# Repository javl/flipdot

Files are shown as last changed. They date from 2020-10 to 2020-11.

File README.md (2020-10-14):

### Work in progress! This project is not completed yet!

# Flipdot
A controller for flipdot displays using the FP2800A BROSE chip. The schematic is heavily based on / pretty much a clone of [flippie](https://github.com/545ch4/flippie). See the flippie repo for a great explaination of how the BROSE displays are controlled.

Changes I have made / are planning on making are:

  * [X] Made in the open source Kicad instead of Eagle
  * [X] Replaced the TBD62783A which a A2982 as it seams easier to find
  * [ ] On-board power conversion instead of needing separate inputs for 3.3V, 5V and 24V

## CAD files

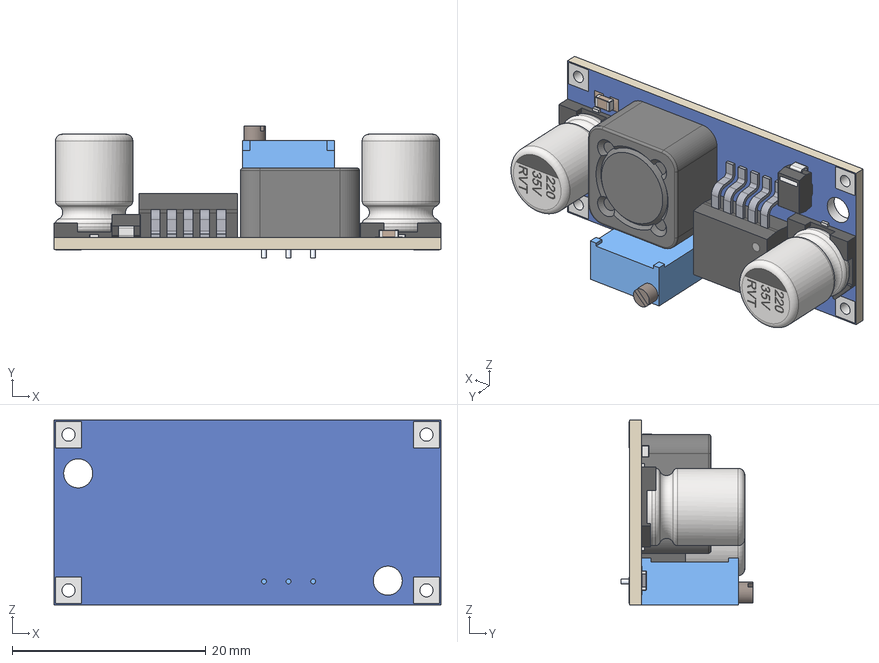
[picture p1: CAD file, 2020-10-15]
3dshapes/LM2596 DC-DC Buck Converter Module.stp
40.0 x 13.7 x 19.1 mm
CAPSMD220-35 x 2
Diode SMA
solder_hole x 4

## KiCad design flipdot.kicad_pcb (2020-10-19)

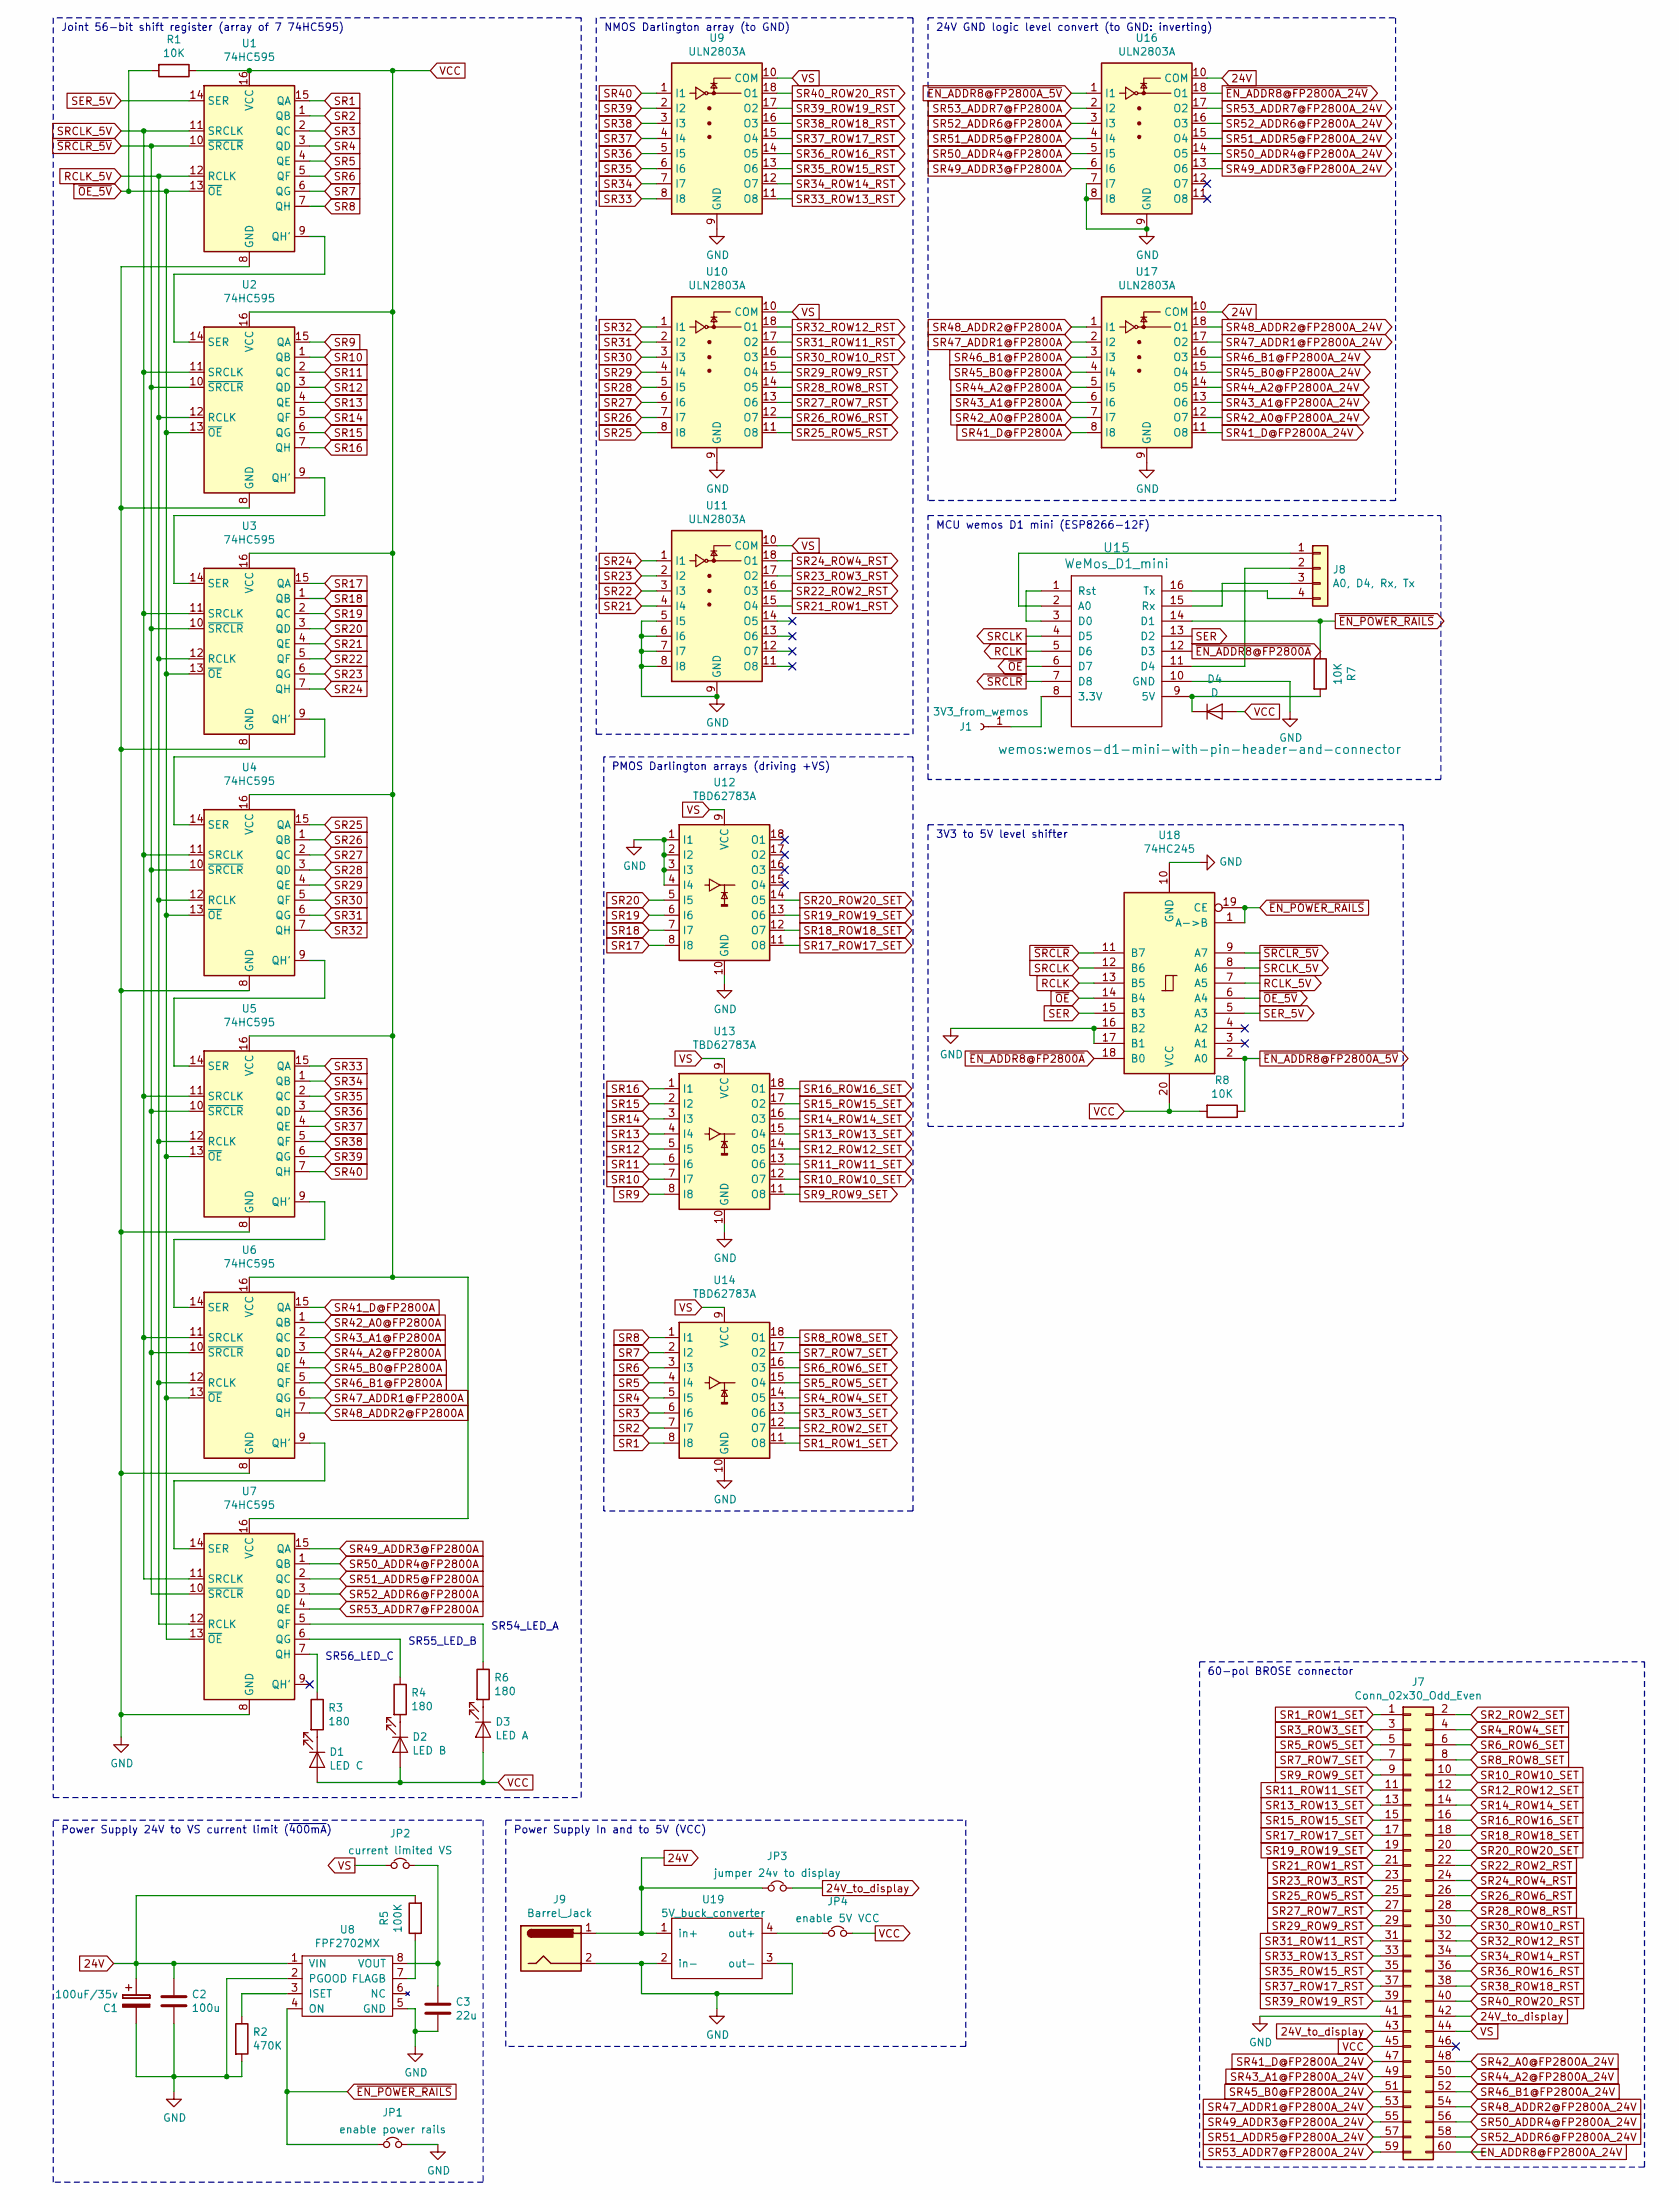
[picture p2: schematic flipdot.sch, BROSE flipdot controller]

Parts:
C1: 100uF/35v; CP_Elec_6.3x7.7
C2: 100u; CP_Radial_D6.3mm_P2.50mm
C3: 22u; CP_Radial_D5.0mm_P2.00mm
D1: LED C; LED_0805_2012Metric
D2: LED B; LED_0805_2012Metric
D3: LED A; LED_0805_2012Metric
D4: D; D_A-405_P7.62mm_Horizontal
J1: 3V3_from_wemos; PinHeader_1x01_P2.54mm_Vertical
J7: Conn_02x30_Odd_Even; PinHeader_2x30_P2.54mm_Vertical
J8: A0, D4, Rx, Tx; PinHeader_1x04_P2.54mm_Vertical
J9: Barrel_Jack; BarrelJack_Wuerth_6941xx301002
JP1: enable power rails; PinHeader_1x02_P2.54mm_Vertical
JP2: current limited VS; PinHeader_1x02_P2.54mm_Vertical
JP3: jumper 24v to display; PinHeader_1x02_P2.54mm_Vertical
JP4: enable 5V VCC; PinHeader_1x02_P2.54mm_Vertical
R1, R7, R8: 10K; R_0805_2012Metric
R2: 470K; R_0603_1608Metric
R3, R4, R6: 180; R_0603_1608Metric
R5: 100K; R_0603_1608Metric
U1, U2, U3, U4, U5, U6, U7: 74HC595; SOIC-16_3.9x9.9mm_P1.27mm
U8: FPF2702MX; SOIC-8_3.9x4.9mm_P1.27mm
U9, U10, U11, U16, U17: ULN2803A; SOIC-18W_7.5x11.6mm_P1.27mm
U12, U13, U14: TBD62783A; SOIC-20W_7.5x12.8mm_P1.27mm
U15: WeMos_D1_mini; wemos-d1-mini-with-pin-header-and-connector
U18: 74HC245; SO-20_12.8x7.5mm_P1.27mm
U19: 5V_buck_converter; 5v_buck_converter

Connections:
24V: C1.1, C2.1, J9.1, JP3.1, R5.2, U8.1 (VIN), U16.10 (COM), U17.10 (COM), U19.1 (in+)
24V_to_display: J7.42, J7.43, JP3.2
unnamed: C3.1, JP2.2, U8.8 (VOUT)
unnamed: D1.1 (K), R3.2
unnamed: D2.1 (K), R4.2
unnamed: D3.1 (K), R6.2
unnamed: D4.1 (K), R7.2, U15.9 (5V)
unnamed: J1.1, U15.8 (3.3V)
unnamed: J8.1, U15.2 (A0)
unnamed: J8.2, U15.11 (D4)
unnamed: J8.3, U15.15 (Rx)
unnamed: J8.4, U15.16 (Tx)
unnamed: JP4.1, U19.4 (out+)
unnamed: R2.1, U8.3 (ISET)
unnamed: R3.1, U7.7 (QH)
unnamed: R4.1, U7.6 (QG)
unnamed: R5.1, U8.7 (FLAGB)
unnamed: R6.1, U7.5 (QF)
unnamed: U1.9 (QH'), U2.14 (SER)
unnamed: U2.9 (QH'), U3.14 (SER)
unnamed: U3.9 (QH'), U4.14 (SER)
unnamed: U4.9 (QH'), U5.14 (SER)
unnamed: U5.9 (QH'), U6.14 (SER)
unnamed: U6.9 (QH'), U7.14 (SER)
unnamed: U15.1 (Rst), U15.3 (D0)
RCLK: U15.5 (D6), U18.13 (B5)
RCLK_5V: U1.12 (RCLK), U2.12 (RCLK), U3.12 (RCLK), U4.12 (RCLK), U5.12 (RCLK), U6.12 (RCLK), U7.12 (RCLK), U18.7 (A5)
SER: U15.13 (D2), U18.15 (B3)
SER_5V: U1.14 (SER), U18.5 (A3)
SR1: U1.15 (QA), U14.8 (I8)
SR1_ROW1_SET: J7.1, U14.11 (O8)
SR2: U1.1 (QB), U14.7 (I7)
SR2_ROW2_SET: J7.2, U14.12 (O7)
SR3: U1.2 (QC), U14.6 (I6)
SR3_ROW3_SET: J7.3, U14.13 (O6)
SR4: U1.3 (QD), U14.5 (I5)
SR4_ROW4_SET: J7.4, U14.14 (O5)
SR5: U1.4 (QE), U14.4 (I4)
SR5_ROW5_SET: J7.5, U14.15 (O4)
SR6: U1.5 (QF), U14.3 (I3)
SR6_ROW6_SET: J7.6, U14.16 (O3)
SR7: U1.6 (QG), U14.2 (I2)
SR7_ROW7_SET: J7.7, U14.17 (O2)
SR8: U1.7 (QH), U14.1 (I1)
SR8_ROW8_SET: J7.8, U14.18 (O1)
SR9: U2.15 (QA), U13.8 (I8)
SR9_ROW9_SET: J7.9, U13.11 (O8)
SR10: U2.1 (QB), U13.7 (I7)
SR10_ROW10_SET: J7.10, U13.12 (O7)
SR11: U2.2 (QC), U13.6 (I6)
SR11_ROW11_SET: J7.11, U13.13 (O6)
SR12: U2.3 (QD), U13.5 (I5)
SR12_ROW12_SET: J7.12, U13.14 (O5)
SR13: U2.4 (QE), U13.4 (I4)
SR13_ROW13_SET: J7.13, U13.15 (O4)
SR14: U2.5 (QF), U13.3 (I3)
SR14_ROW14_SET: J7.14, U13.16 (O3)
SR15: U2.6 (QG), U13.2 (I2)
SR15_ROW15_SET: J7.15, U13.17 (O2)
SR16: U2.7 (QH), U13.1 (I1)
SR16_ROW16_SET: J7.16, U13.18 (O1)
SR17: U3.15 (QA), U12.8 (I8)
SR17_ROW17_SET: J7.17, U12.11 (O8)
SR18: U3.1 (QB), U12.7 (I7)
SR18_ROW18_SET: J7.18, U12.12 (O7)
SR19: U3.2 (QC), U12.6 (I6)
SR19_ROW19_SET: J7.19, U12.13 (O6)
SR20: U3.3 (QD), U12.5 (I5)
SR20_ROW20_SET: J7.20, U12.14 (O5)
SR21: U3.4 (QE), U11.4 (I4)
SR21_ROW1_RST: J7.21, U11.15 (O4)
SR22: U3.5 (QF), U11.3 (I3)
SR22_ROW2_RST: J7.22, U11.16 (O3)
SR23: U3.6 (QG), U11.2 (I2)
SR23_ROW3_RST: J7.23, U11.17 (O2)
SR24: U3.7 (QH), U11.1 (I1)
SR24_ROW4_RST: J7.24, U11.18 (O1)
SR25: U4.15 (QA), U10.8 (I8)
SR25_ROW5_RST: J7.25, U10.11 (O8)
SR26: U4.1 (QB), U10.7 (I7)
SR26_ROW6_RST: J7.26, U10.12 (O7)
SR27: U4.2 (QC), U10.6 (I6)
SR27_ROW7_RST: J7.27, U10.13 (O6)
SR28: U4.3 (QD), U10.5 (I5)
SR28_ROW8_RST: J7.28, U10.14 (O5)
SR29: U4.4 (QE), U10.4 (I4)
SR29_ROW9_RST: J7.29, U10.15 (O4)
SR30: U4.5 (QF), U10.3 (I3)
SR30_ROW10_RST: J7.30, U10.16 (O3)
SR31: U4.6 (QG), U10.2 (I2)
SR31_ROW11_RST: J7.31, U10.17 (O2)
SR32: U4.7 (QH), U10.1 (I1)
SR32_ROW12_RST: J7.32, U10.18 (O1)
SR33: U5.15 (QA), U9.8 (I8)
SR33_ROW13_RST: J7.33, U9.11 (O8)
SR34: U5.1 (QB), U9.7 (I7)
SR34_ROW14_RST: J7.34, U9.12 (O7)
SR35: U5.2 (QC), U9.6 (I6)
SR35_ROW15_RST: J7.35, U9.13 (O6)
SR36: U5.3 (QD), U9.5 (I5)
SR36_ROW16_RST: J7.36, U9.14 (O5)
SR37: U5.4 (QE), U9.4 (I4)
SR37_ROW17_RST: J7.37, U9.15 (O4)
SR38: U5.5 (QF), U9.3 (I3)
SR38_ROW18_RST: J7.38, U9.16 (O3)
SR39: U5.6 (QG), U9.2 (I2)
SR39_ROW19_RST: J7.39, U9.17 (O2)
SR40: U5.7 (QH), U9.1 (I1)
SR40_ROW20_RST: J7.40, U9.18 (O1)
SR41_D@FP2800A: U6.15 (QA), U17.8 (I8)
SR41_D@FP2800A_24V: J7.47, U17.11 (O8)
SR42_A0@FP2800A: U6.1 (QB), U17.7 (I7)
SR42_A0@FP2800A_24V: J7.48, U17.12 (O7)
SR43_A1@FP2800A: U6.2 (QC), U17.6 (I6)
SR43_A1@FP2800A_24V: J7.49, U17.13 (O6)
SR44_A2@FP2800A: U6.3 (QD), U17.5 (I5)
SR44_A2@FP2800A_24V: J7.50, U17.14 (O5)
SR45_B0@FP2800A: U6.4 (QE), U17.4 (I4)
SR45_B0@FP2800A_24V: J7.51, U17.15 (O4)
SR46_B1@FP2800A: U6.5 (QF), U17.3 (I3)
SR46_B1@FP2800A_24V: J7.52, U17.16 (O3)
SR47_ADDR1@FP2800A: U6.6 (QG), U17.2 (I2)
SR47_ADDR1@FP2800A_24V: J7.53, U17.17 (O2)
SR48_ADDR2@FP2800A: U6.7 (QH), U17.1 (I1)
SR48_ADDR2@FP2800A_24V: J7.54, U17.18 (O1)
SR49_ADDR3@FP2800A: U7.15 (QA), U16.6 (I6)
SR49_ADDR3@FP2800A_24V: J7.55, U16.13 (O6)
SR50_ADDR4@FP2800A: U7.1 (QB), U16.5 (I5)
SR50_ADDR4@FP2800A_24V: J7.56, U16.14 (O5)
SR51_ADDR5@FP2800A: U7.2 (QC), U16.4 (I4)
SR51_ADDR5@FP2800A_24V: J7.57, U16.15 (O4)
SR52_ADDR6@FP2800A: U7.3 (QD), U16.3 (I3)
SR52_ADDR6@FP2800A_24V: J7.58, U16.16 (O3)
SR53_ADDR7@FP2800A: U7.4 (QE), U16.2 (I2)
SR53_ADDR7@FP2800A_24V: J7.59, U16.17 (O2)
SRCLK: U15.4 (D5), U18.12 (B6)
SRCLK_5V: U1.11 (SRCLK), U2.11 (SRCLK), U3.11 (SRCLK), U4.11 (SRCLK), U5.11 (SRCLK), U6.11 (SRCLK), U7.11 (SRCLK), U18.8 (A6)
VCC: D1.2 (A), D2.2 (A), D3.2 (A), D4.2 (A), J7.45, JP4.2, R1.1, R8.2, U1.16 (VCC), U2.16 (VCC), U3.16 (VCC), U4.16 (VCC), U5.16 (VCC), U6.16 (VCC), U7.16 (VCC), U18.20 (VCC)
VS: J7.44, JP2.1, U9.10 (COM), U10.10 (COM), U11.10 (COM), U12.9 (VCC), U13.9 (VCC), U14.9 (VCC)
~EN_ADDR8@FP2800A: U15.12 (D3), U18.18 (B0)
~EN_ADDR8@FP2800A_5V: R8.1, U16.1 (I1), U18.2 (A0)
~EN_POWER_RAILS: JP1.1, R7.1, U8.4 (ON), U15.14 (D1), U18.1 (A->B), U18.19 (CE)
~OE: U15.6 (D7), U18.14 (B4)
~OE_5V: R1.2, U1.13 (~OE), U2.13 (~OE), U3.13 (~OE), U4.13 (~OE), U5.13 (~OE), U6.13 (~OE), U7.13 (~OE), U18.6 (A4)
~SRCLR: U15.7 (D8), U18.11 (B7)
~SRCLR_5V: U1.10 (~SRCLR), U2.10 (~SRCLR), U3.10 (~SRCLR), U4.10 (~SRCLR), U5.10 (~SRCLR), U6.10 (~SRCLR), U7.10 (~SRCLR), U18.9 (A7)

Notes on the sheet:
Joint 56-bit shift register (array of 7 74HC595)
24V GND logic level convert (to GND: inverting)
NMOS Darlington array (to GND)
MCU wemos D1 mini (ESP8266-12F)
Power Supply 24V to VS current limit (~400mA)
PMOS Darlington arrays (driving +VS)
3V3 to 5V level shifter
60-pol BROSE connector
SR54_LED_A
SR55_LED_B
SR56_LED_C
Power Supply In and to 5V (VCC)

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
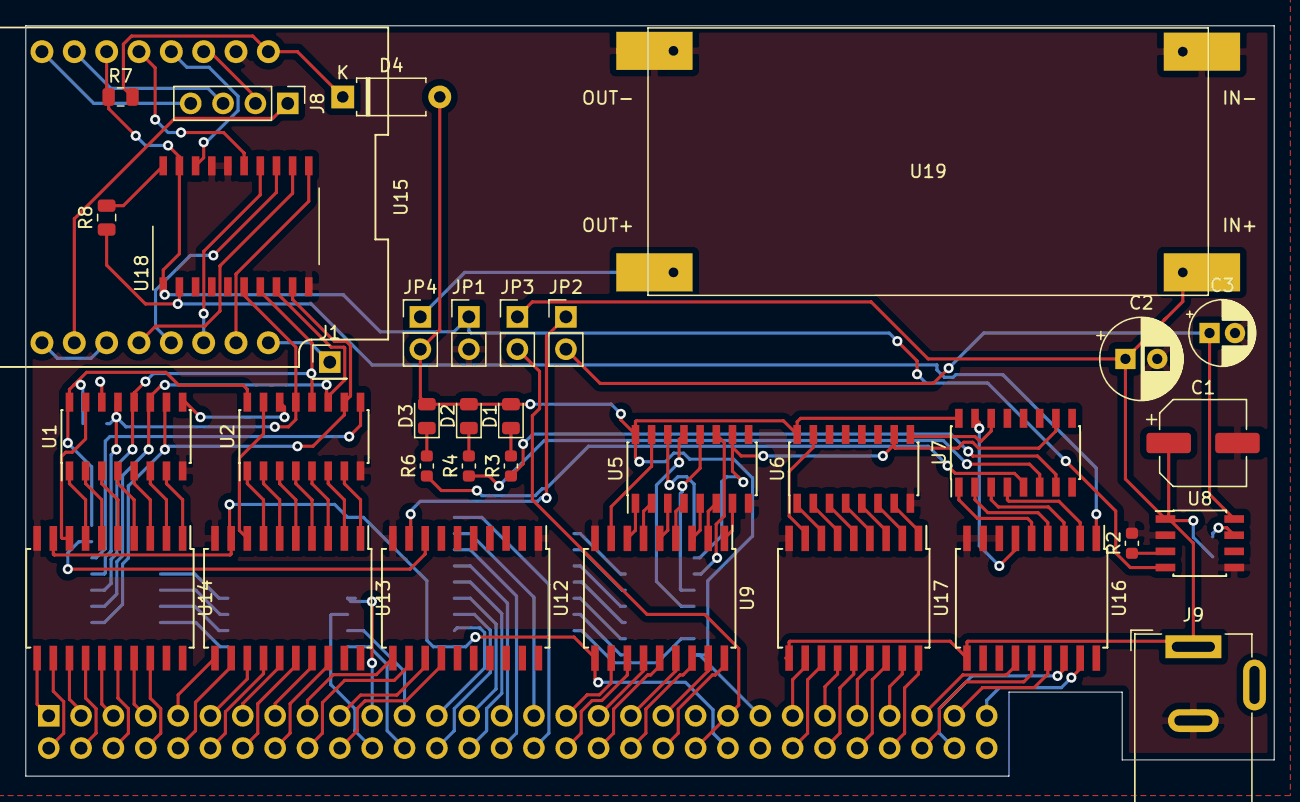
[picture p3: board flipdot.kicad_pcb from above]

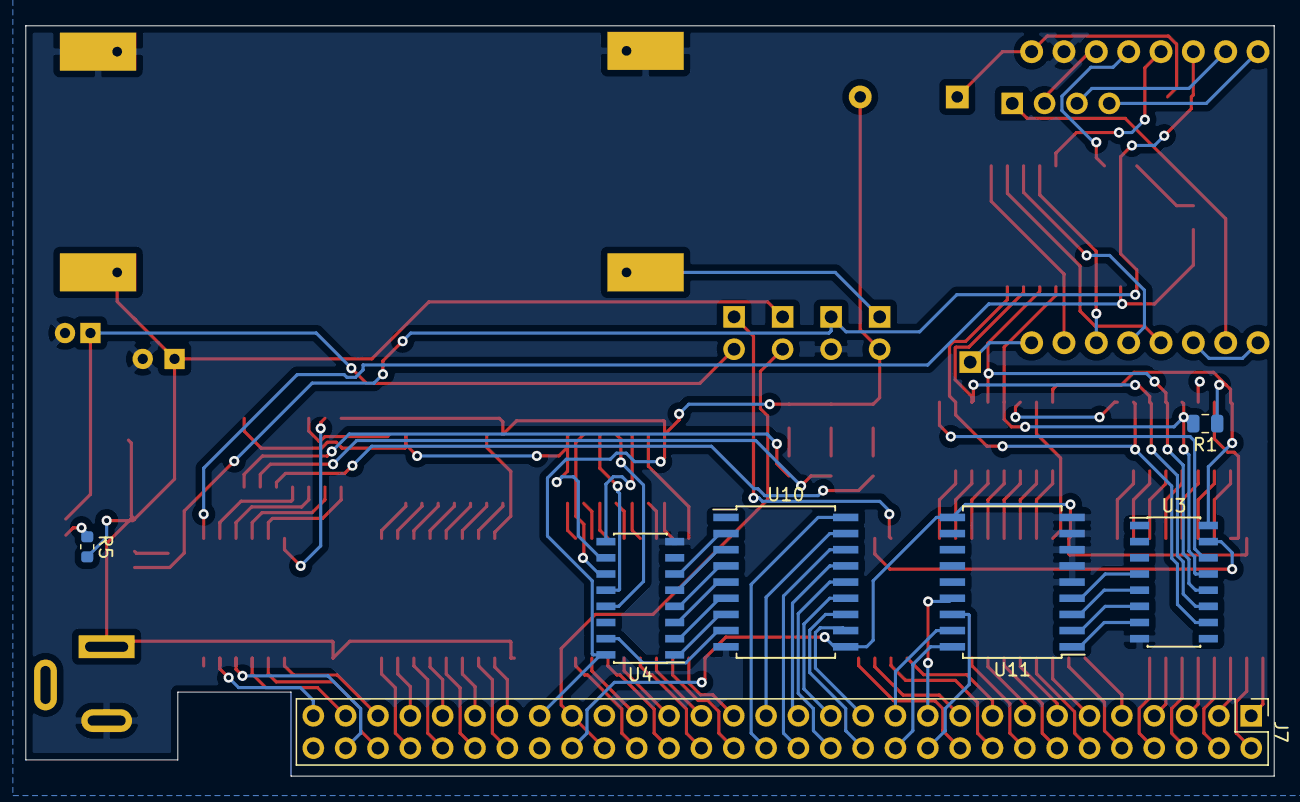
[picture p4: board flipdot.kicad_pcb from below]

Board: 2 copper layers, 98.0 x 58.9 mm, 42 parts (7 on the bottom side), 148 nets.
